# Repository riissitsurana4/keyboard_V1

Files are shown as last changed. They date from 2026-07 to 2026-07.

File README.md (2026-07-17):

# Keyboard_V1
Hello everyone!

This hardware project is a custom keyboard and  macro pad made using switches, a rotatory encoder, etc.

## PCB Design
### Keyboard 
The PCB was designed in **KiCad** and includes the following features:

* Cherry Mx Switches arranged in a matrix 
* Mini leds for underglow
* 2 rotary encoder
* NRF52840 as the MCU
* 1N4148 (diodes)
* 74HC14N and MT3608 to step up current for leds
* 74HC595 - Shift registers

The LEDs are placed under each key for per key under glow.
Using shift registers for columns.

https://kicanvas.org/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

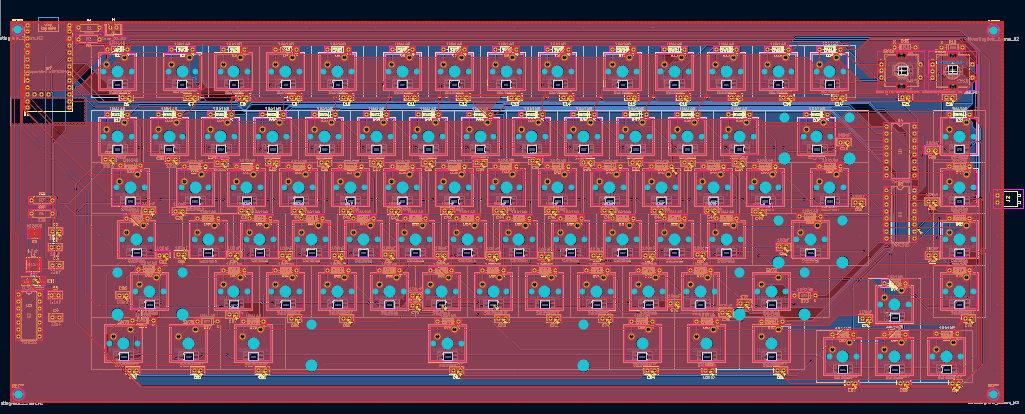
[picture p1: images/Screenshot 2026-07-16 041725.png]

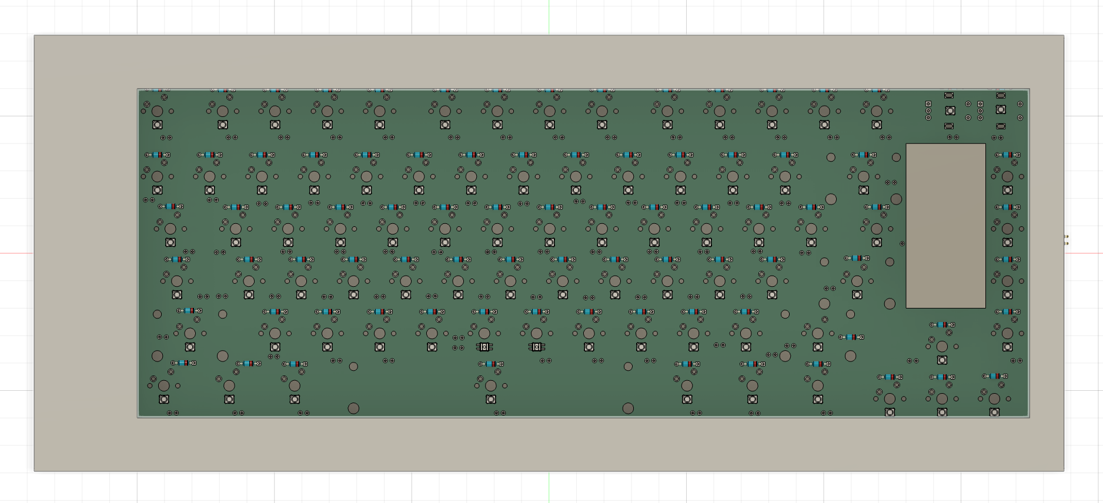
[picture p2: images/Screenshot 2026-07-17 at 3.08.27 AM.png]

### Macro Pad
The PCB was designed in **KiCad** and includes the following features:
* Cherry Mx Switches arranged in a matrix 
* 2 rotary encoder
* NRF52840 as the MCU
* 
https://kicanvas.org/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

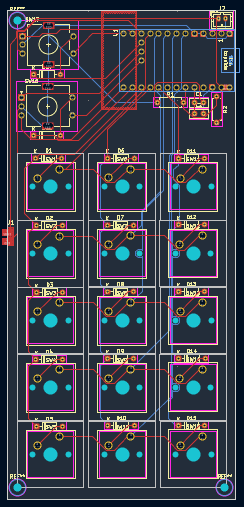
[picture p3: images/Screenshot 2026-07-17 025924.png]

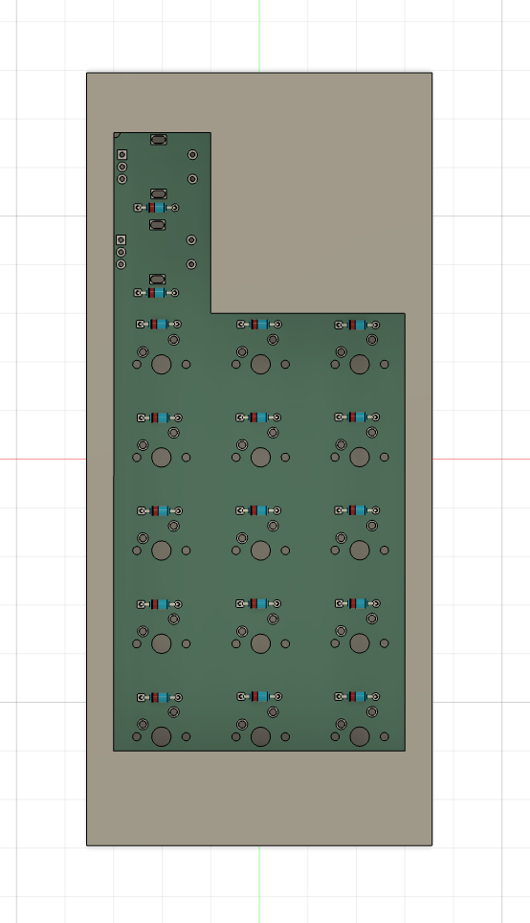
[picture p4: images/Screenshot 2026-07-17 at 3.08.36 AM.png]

Using the NRF in both of them as it can be used wirelessly together

Both of the pcbs have a battery connector.

## Firmware
The firmware for this project is written in ZMK.
MAjor part of the firmware is AI written, mainly the keyboard part as i could not get the shift resistors part to work by myself.
It is located in a different repo 
https://github.com/riissitsurana4/keyboard_zmk
You can find the latest build at https://github.com/riissitsurana4/keyboard_zmk/actions/runs/29620562583

## Instructions
If you want to create this keyboard for yourself, you can find the pcb and the case designs in this repo. The case is designed to be 3d printed. 
Please refer to the above firmware section to download the latest version. You will need to flash both the mcu's with the latest build. 

NOTE: For the macropad PCB you would need to order a perforated side pcb so that the copper pads will flow over to the sides and make the pogo pin connection better. 

## BOM
| Item | Part Number | Quantity | Link |
|---|---|---|---|
| Microcontroller | nRF52840 | 2 | https://robu.in/product/promicro-nrf52840-development-board/ |
| Diode | 1N4148 | | https://stackskb.com/store/1n4148-through-hole-diode/ |
| Shift Register | 74HC595 | 2 | https://robu.in/product/1-month-warranty-1354/ |
| Hex Schmitt Trigger | 74HC14N | 1 | https://robu.in/product/sn74hct14n-texas-instruments-logic-ic-inverter-hex-1-inputs-14-pins-dip-74hct14/ |
| DC-DC Boost Converter | MT3608 | 1 | https://robu.in/product/mt3608-xian-aerosemi-tech-boost-type-adjustable-2a-2v24v-sot-23-6-dc-dc-converters-rohs/ |
| Mini LEDs | SK6812 MINI |~90 |  |
| LiPo Battery | 2000 mAh | 1 |  |
| LiPo Battery | 300 mAh | 1 |  |
| Battery Connector | JST-PH 2.0 (2-pin) | 2 |  |
| Switches | Cherry-MX switches | ~100 |https://stackskb.com/store/akko-v3-cream-black-pro-switch-pack-of-45/  |

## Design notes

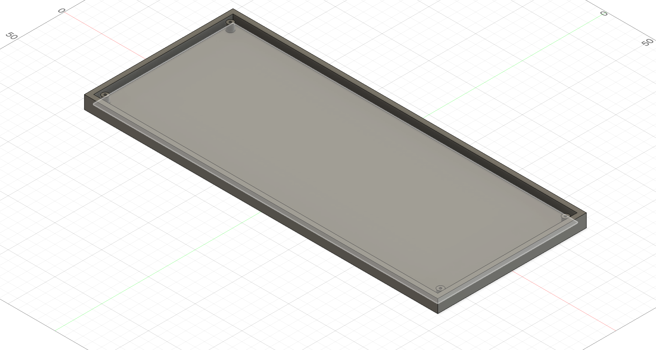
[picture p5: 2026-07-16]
images/Screenshot 2026-07-16 at 4.36.15 AM.png

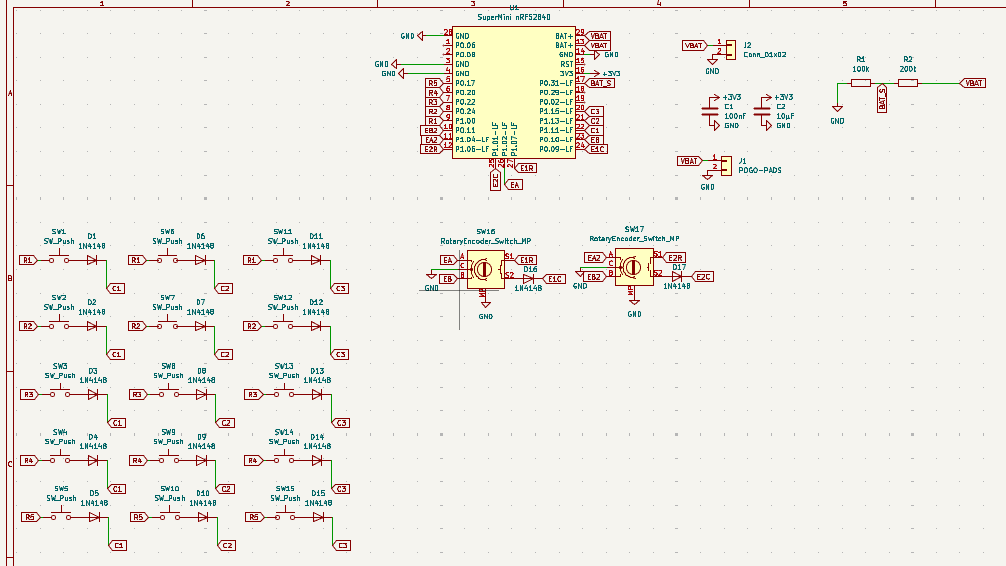
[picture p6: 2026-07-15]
images/Screenshot 2026-07-15 112258.png

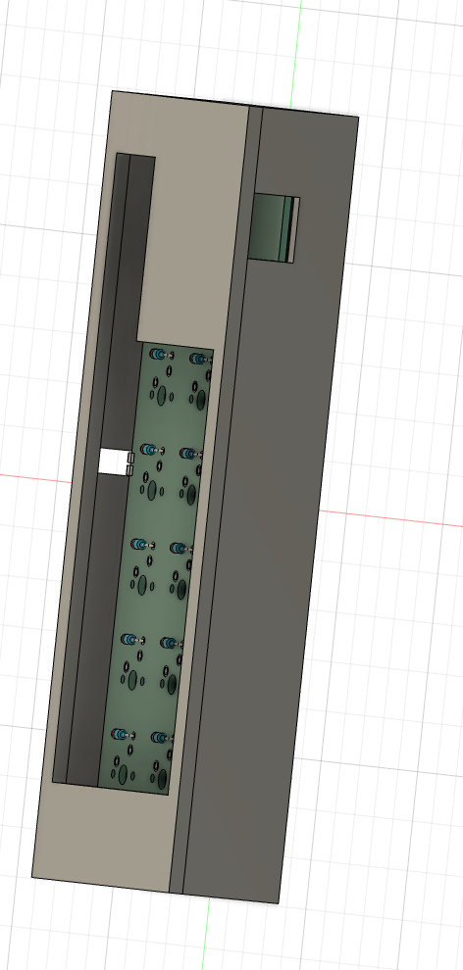
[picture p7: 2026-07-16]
images/Screenshot 2026-07-17 at 3.09.45 AM.png

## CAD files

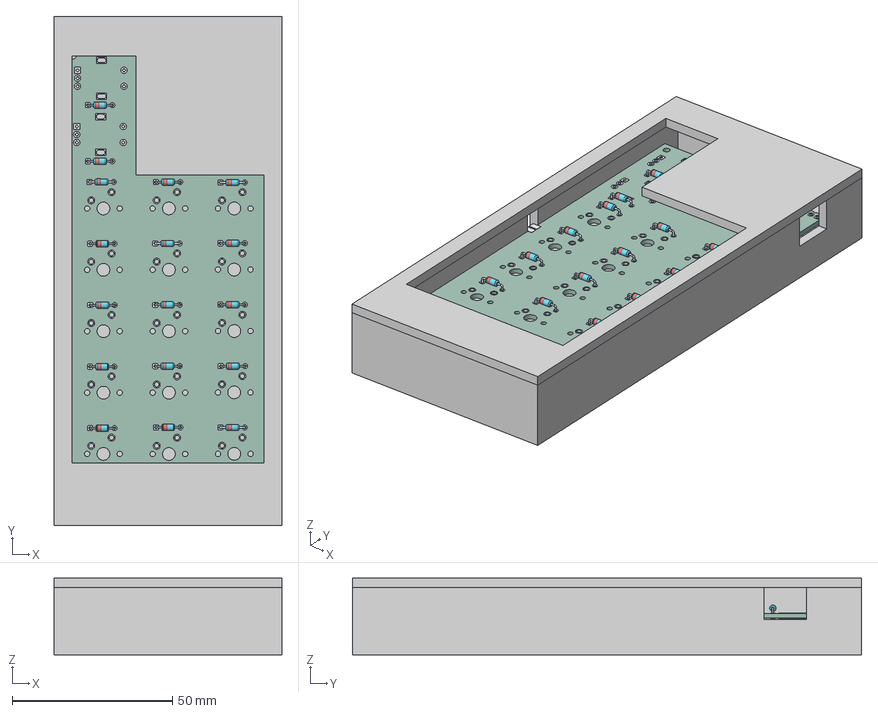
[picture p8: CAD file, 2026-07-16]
CASE - CAD/macropad_case.step
71.2 x 159.0 x 24.0 mm

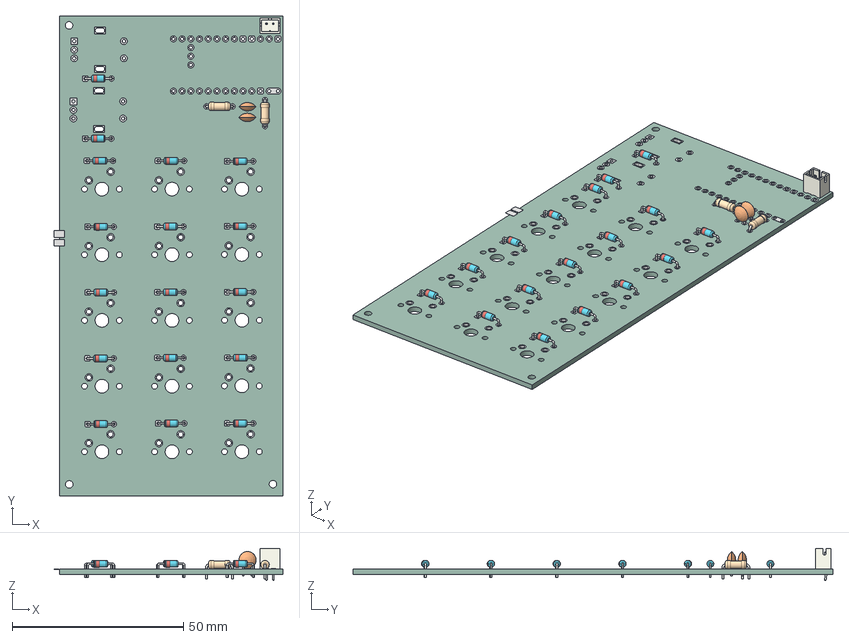
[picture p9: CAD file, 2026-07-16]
PCB/Macropad/macropad_pcb.step
66.7 x 140.0 x 9.40 mm
D_DO-35_SOD27_P7.62mm_Horizontal x 17
R_Axial_DIN0207_L6.3mm_D2.5mm_P7.62mm_Horizontal x 2
JST_PH_B2B-PH-K_1x02_P2.00mm_Vertical
C_Disc_D5.0mm_W2.5mm_P2.50mm x 2
macropad-v2_pad
macropad-v2_PCB

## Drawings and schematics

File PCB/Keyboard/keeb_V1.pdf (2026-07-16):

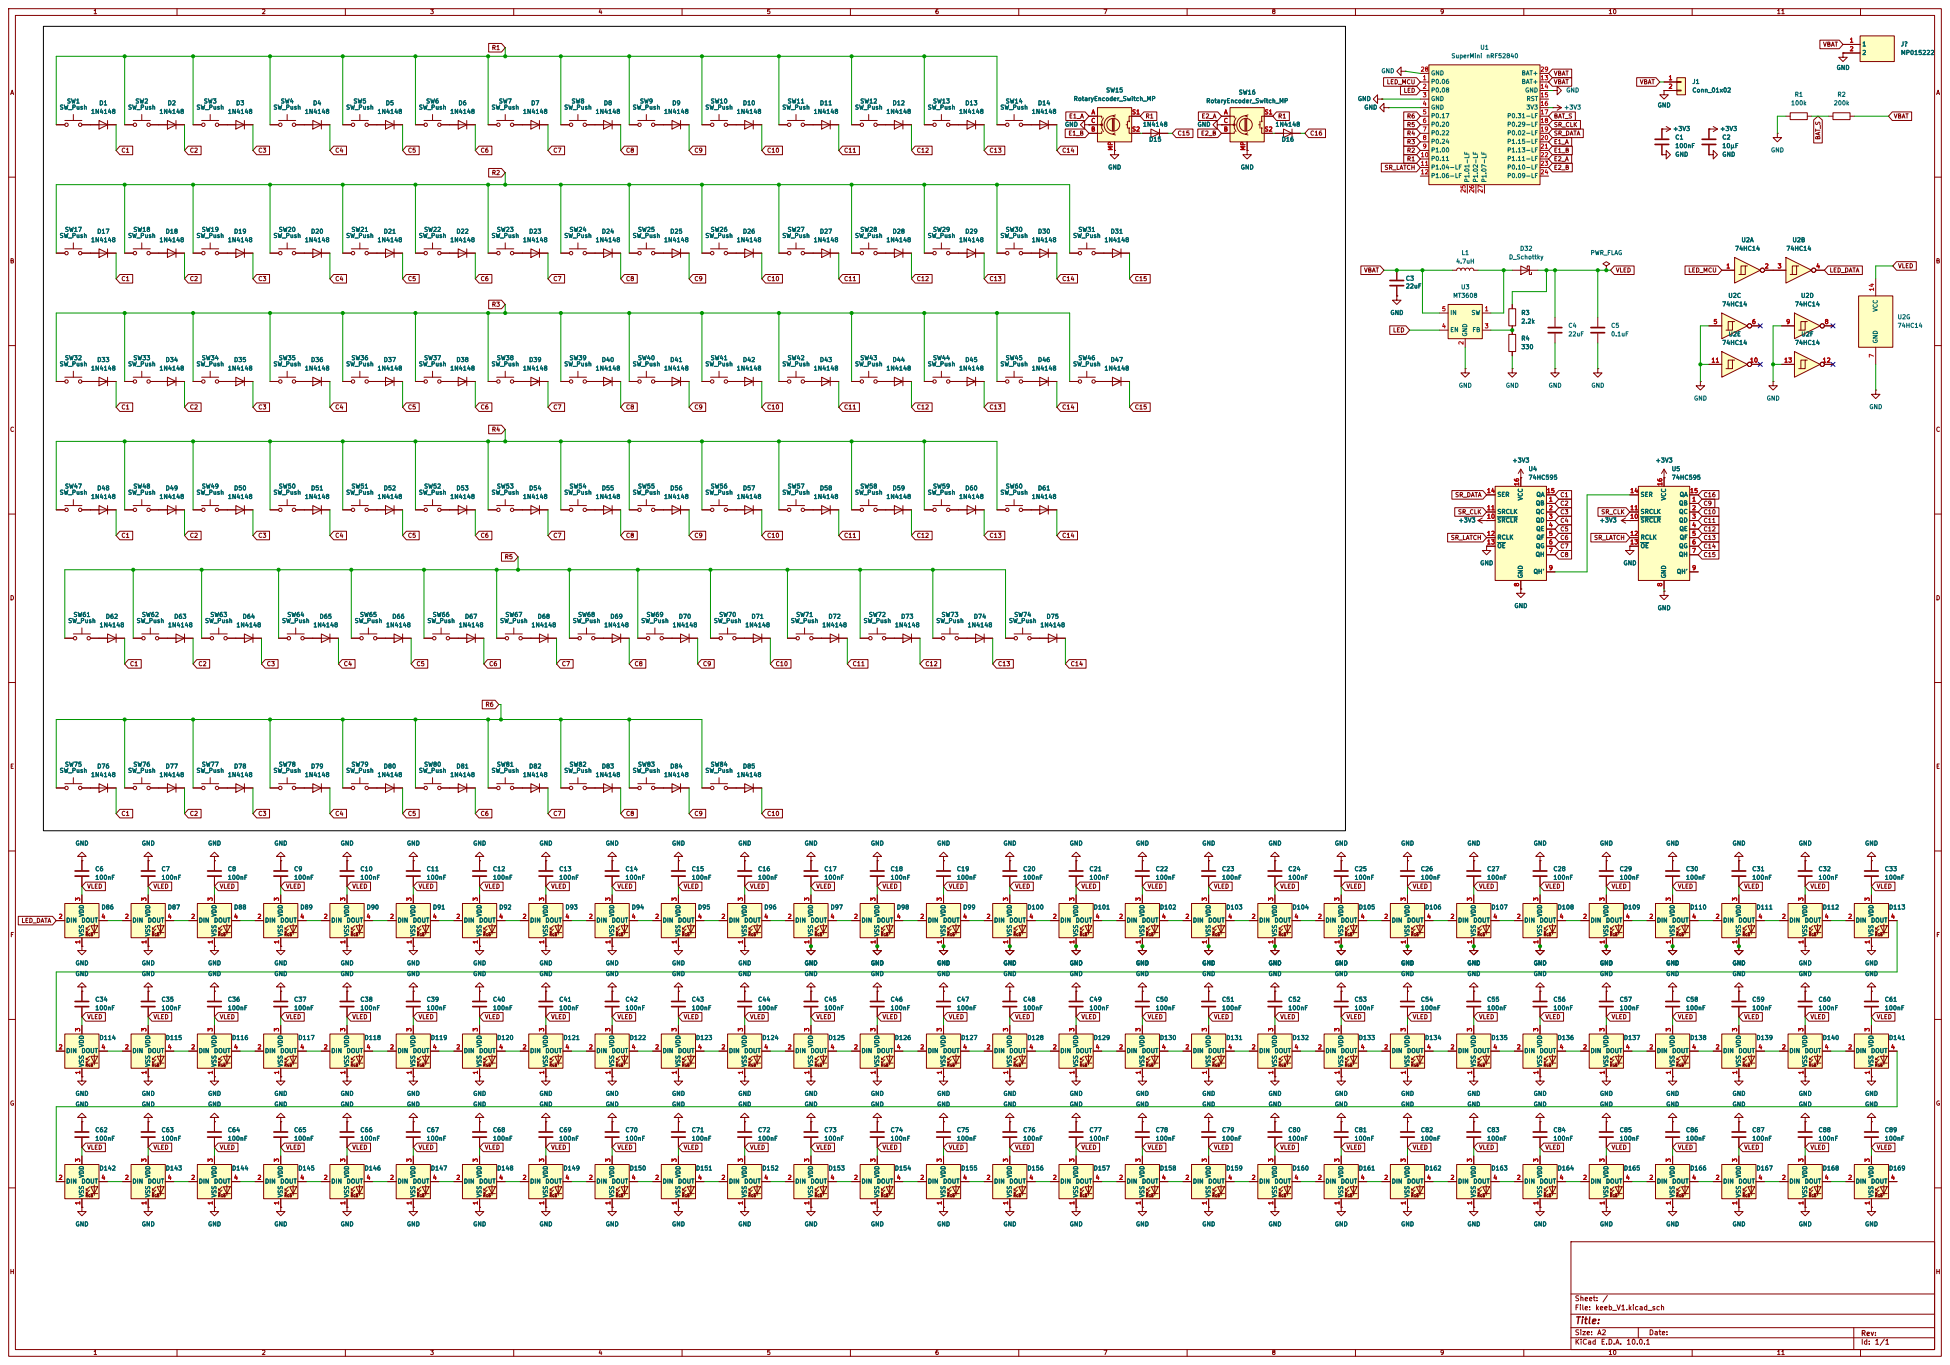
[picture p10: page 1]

14 RST 15 P0.31-LF 17 P0.29-LF 18 P0.02-LF 19 P1.15-LF 20 P1.13-LF 21 P1.11-LF 22 P0.09-LF 24 BAT+
VBAT VLED

3 DOUT 4D111 GNDVSS RGB 1 DIN

3 DOUT 4D105 GND GND VSS RGB 1 DIN 2 VDD

3 DOUT 4D102 GND VSS RGB 1 DIN 2 VDD

3 DOUT 4D104 GNDVSS RGB 1 DIN 2 VDD

3 DOUT 4D87 GND GNDVSS RGB 1 DIN 2 VDD

3 DOUT 4D91 VSS RGB 1 DIN

3 DOUT 4D92 GNDVSS RGB 1 DIN

3 DOUT 4D94 VSS RGB 1 DIN 2 VDD

3 DOUT 4 GND GND GND

3 DOUT 4D112 VSS RGB 1 DIN

3 DOUT 4D123 VSS RGB 1 DIN 2 VDD

3 DOUT 4D145 GND GND VSS RGB 1 DIN

3 DOUT 4D118 GND VSS RGB 1 DIN

100nF GND VSS RGB 1 DIN

3 DOUT 4D121 VSS RGB 1 DIN 2 VDD

3 DOUT 4D131 GND GNDVSS RGB 1 DIN 2 VDD

3 DOUT 4D117 GNDVSS RGB 1 DIN

3 DOUT 4D140 GND VSS RGB 1 DIN 2 VDD

3 DOUT 4D125 VSS RGB 1 DIN 2 VDD

3 DOUT 4D127 GND VSS RGB 1 DIN 2 VDD

3 DOUT 4D132 VSS RGB 1 DIN

3 DOUT 4D134 VSS RGB 1 DIN

3 DOUT 4D147 VSS RGB 1 DIN

3 DOUT 4D162 GND GND VSS RGB 1 DIN

3 DOUT 4D142 GND GNDVSS RGB 1 DIN 2 VDD

3 DOUT 4 GND GND GND GND GND GND

3 DOUT 4D157 VSS RGB 1 DIN 2 VDD

3 DOUT 4D156 VSS RGB 1 DIN 2 VDD

3 DOUT 4 GND GND GND GND

3 DOUT 4D158 VSS RGB 1 DIN

Size: A2 | Rev:
KiCad E.D.A. 10.0.1 | Id: 1/1

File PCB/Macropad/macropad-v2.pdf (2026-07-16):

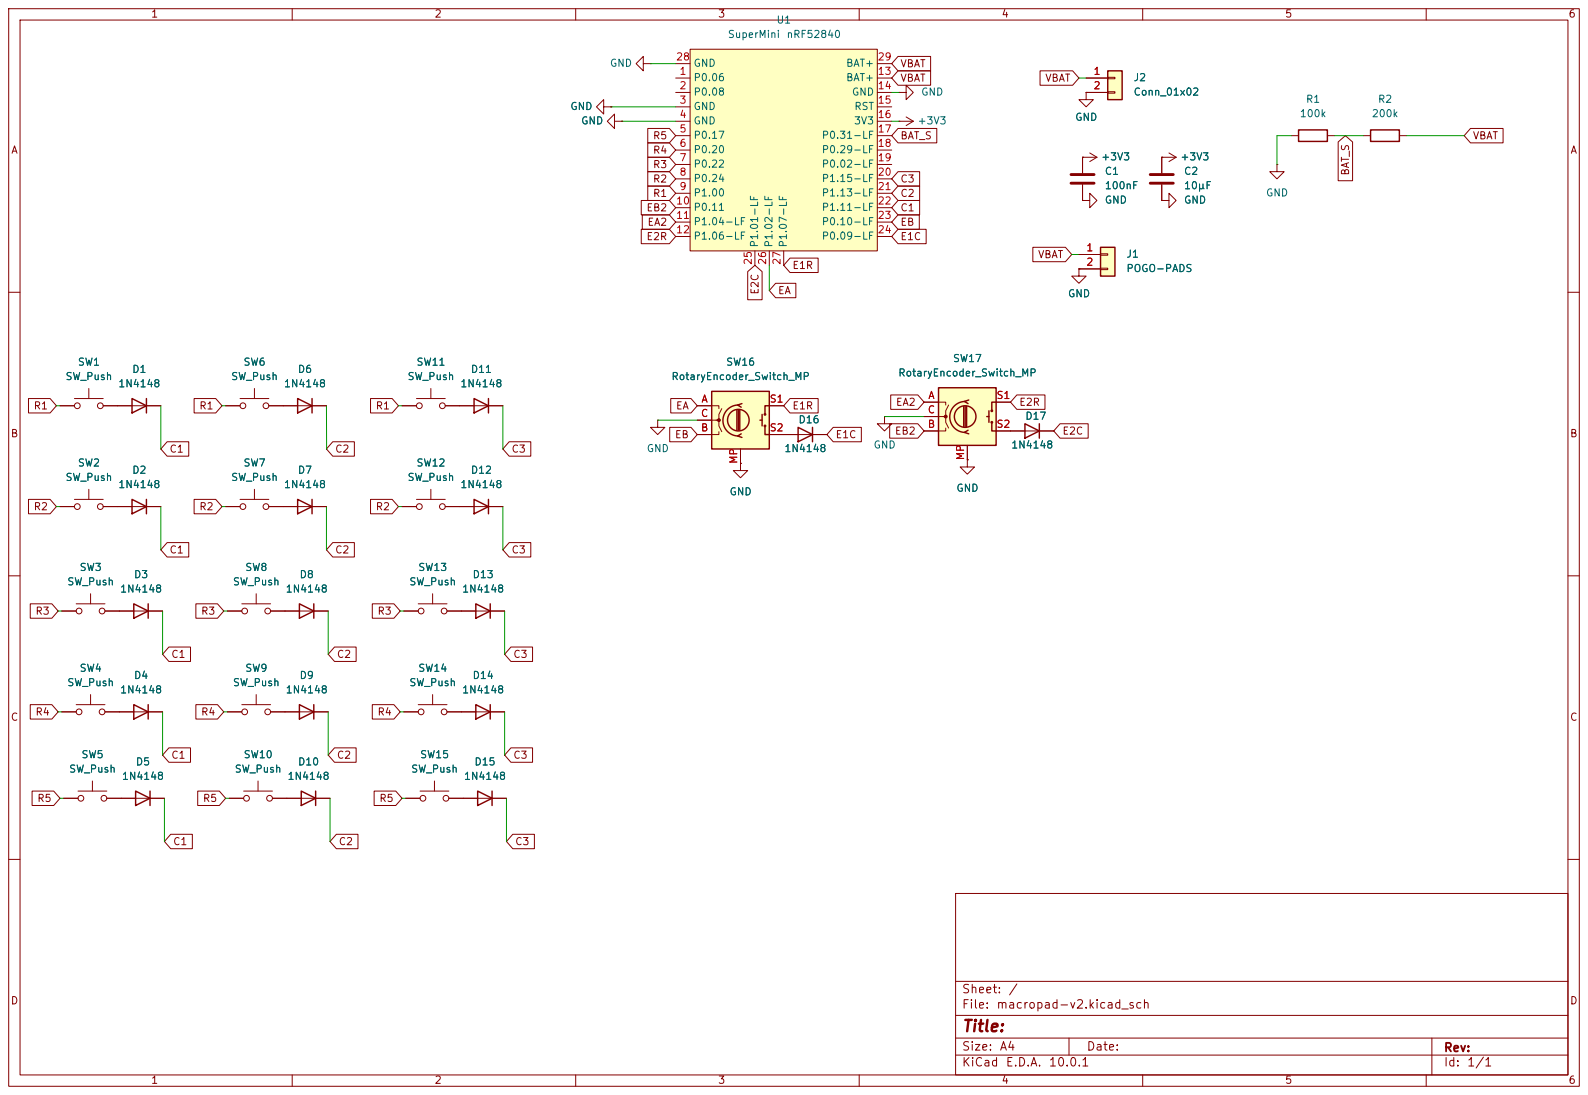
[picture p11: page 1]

Size: A4 | Rev:
KiCad E.D.A. 10.0.1 | Id: 1/1

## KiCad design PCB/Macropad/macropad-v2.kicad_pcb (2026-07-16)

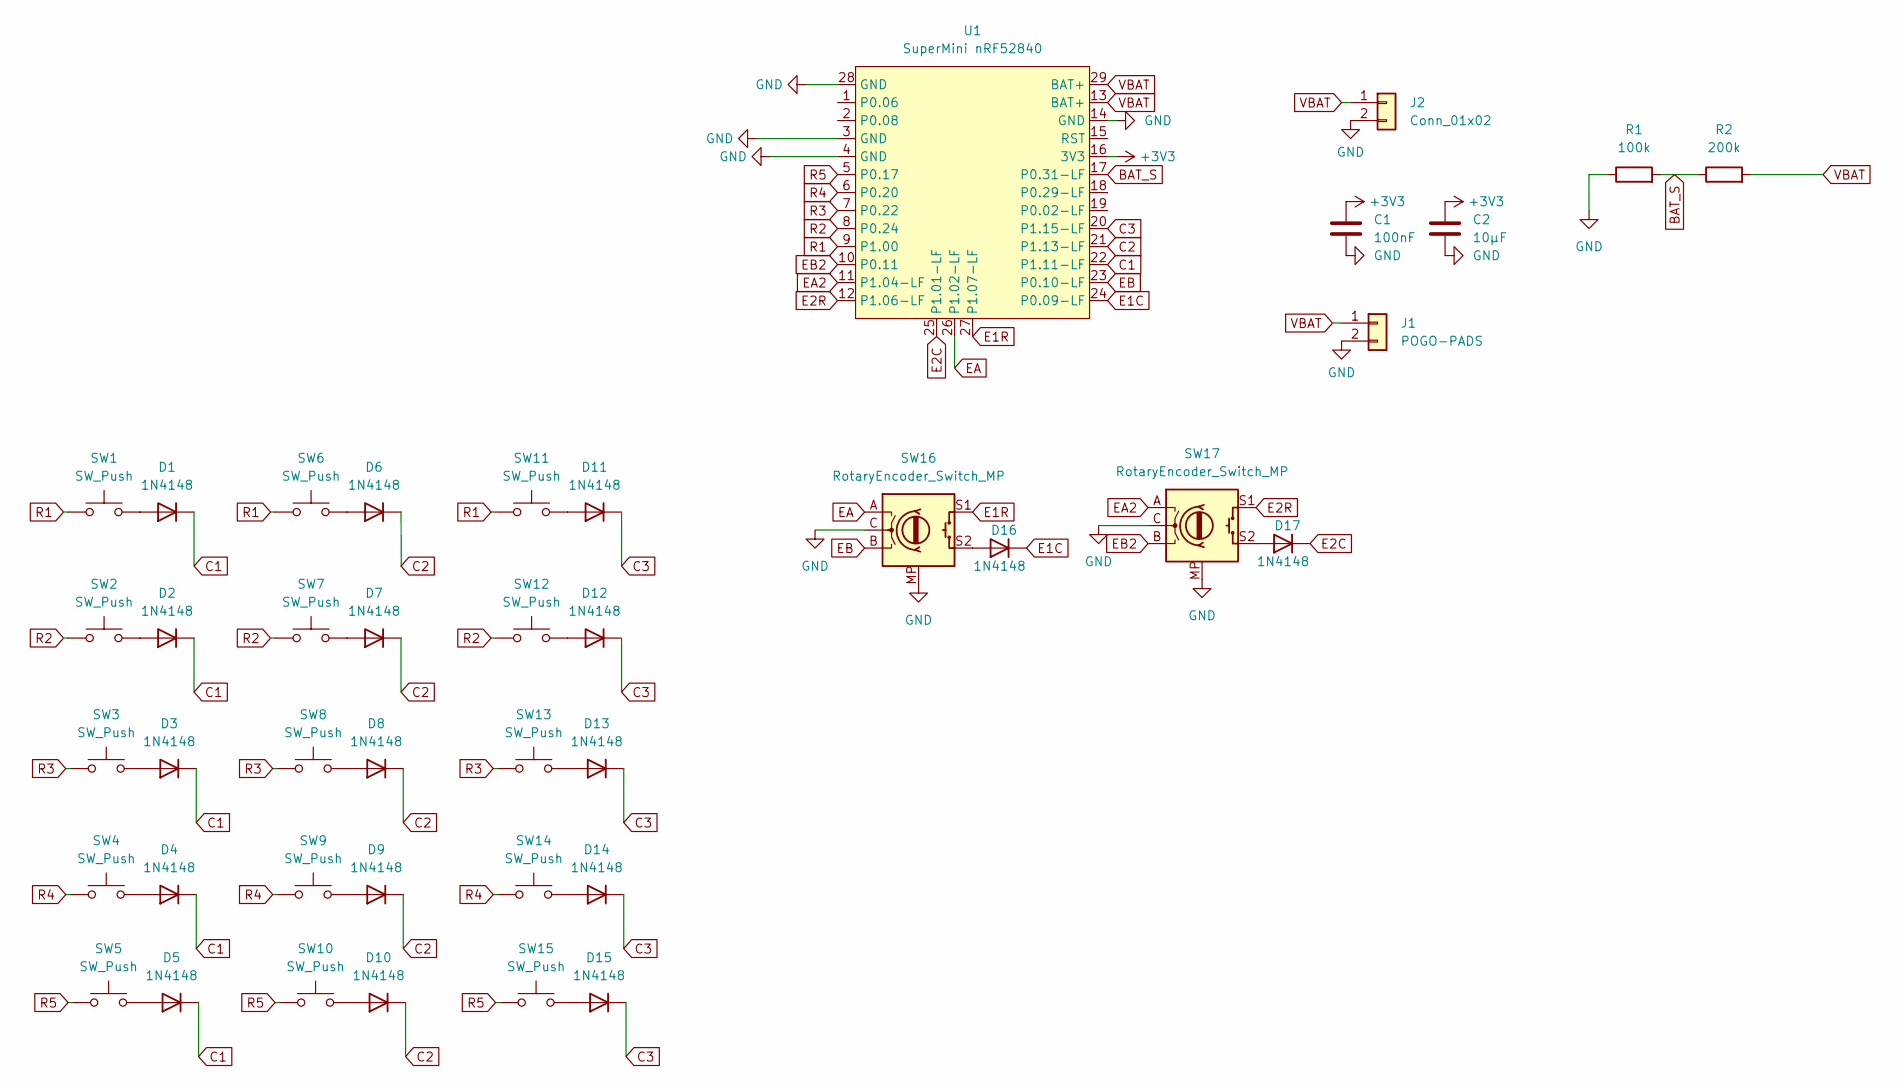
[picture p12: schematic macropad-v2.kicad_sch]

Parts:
C1: 100nF; C_Disc_D5.0mm_W2.5mm_P2.50mm
C2: 10µF; C_Disc_D5.0mm_W2.5mm_P2.50mm
D1, D2, D3, D4, D5, D6, D7, D8, D9, D10, D11, D12, D13, D14, D15, D16, D17: 1N4148; D_DO-35_SOD27_P7.62mm_Horizontal
J1: POGO-PADS; JST_PH_B2B-PH-K_1x02_P2.00mm_Vertical
J2: Conn_01x02; JST_PH_B2B-PH-K_1x02_P2.00mm_Vertical
R1: 100k; R_Axial_DIN0207_L6.3mm_D2.5mm_P7.62mm_Horizontal
R2: 200k; R_Axial_DIN0207_L6.3mm_D2.5mm_P7.62mm_Horizontal
SW1, SW2, SW3, SW4, SW5, SW6, SW7, SW8, SW9, SW10, SW11, SW12, SW13, SW14, SW15: SW_Push; SW_Cherry_MX_1.00u_PCB
SW16, SW17: RotaryEncoder_Switch_MP; RotaryEncoder_Alps_EC11E-Switch_Vertical_H20mm
U1: SuperMini nRF52840; nice_nano_AH_USBup

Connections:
+3V3: C1.1, C2.1, U1.16 (3V3)
BAT_S: R1.2, R2.1, U1.17 (P0.31-LF)
C1: D1.1 (K), D2.1 (K), D3.1 (K), D4.1 (K), D5.1 (K), U1.22 (P1.11-LF)
C2: D6.1 (K), D7.1 (K), D8.1 (K), D9.1 (K), D10.1 (K), U1.21 (P1.13-LF)
C3: D11.1 (K), D12.1 (K), D13.1 (K), D14.1 (K), D15.1 (K), U1.20 (P1.15-LF)
E1C: D16.1 (K), U1.24 (P0.09-LF)
E1R: SW16.S1, U1.27 (P1.07-LF)
E2C: D17.1 (K), U1.25 (P1.01-LF)
E2R: SW17.S1, U1.12 (P1.06-LF)
EA: SW16.A, U1.26 (P1.02-LF)
EA2: SW17.A, U1.11 (P1.04-LF)
EB: SW16.B, U1.23 (P0.10-LF)
EB2: SW17.B, U1.10 (P0.11)
GND: C1.2, C2.2, J1.2, J2.2, R1.1, SW16.C, SW16.MP, SW17.C, SW17.MP, U1.3 (GND), U1.4 (GND), U1.14 (GND), U1.28 (GND)
unnamed: D1.2 (A), SW1.2
unnamed: D2.2 (A), SW2.2
unnamed: D3.2 (A), SW3.2
unnamed: D4.2 (A), SW4.2
unnamed: D5.2 (A), SW5.2
unnamed: D6.2 (A), SW6.2
unnamed: D7.2 (A), SW7.2
unnamed: D8.2 (A), SW8.2
unnamed: D9.2 (A), SW9.2
unnamed: D10.2 (A), SW10.2
unnamed: D11.2 (A), SW11.2
unnamed: D12.2 (A), SW12.2
unnamed: D13.2 (A), SW13.2
unnamed: D14.2 (A), SW14.2
unnamed: D15.2 (A), SW15.2
unnamed: D16.2 (A), SW16.S2
unnamed: D17.2 (A), SW17.S2
R1: SW1.1, SW6.1, SW11.1, U1.9 (P1.00)
R2: SW2.1, SW7.1, SW12.1, U1.8 (P0.24)
R3: SW3.1, SW8.1, SW13.1, U1.7 (P0.22)
R4: SW4.1, SW9.1, SW14.1, U1.6 (P0.20)
R5: SW5.1, SW10.1, SW15.1, U1.5 (P0.17)
VBAT: J1.1, J2.1, R2.2, U1.13 (BAT+), U1.29 (BAT+)

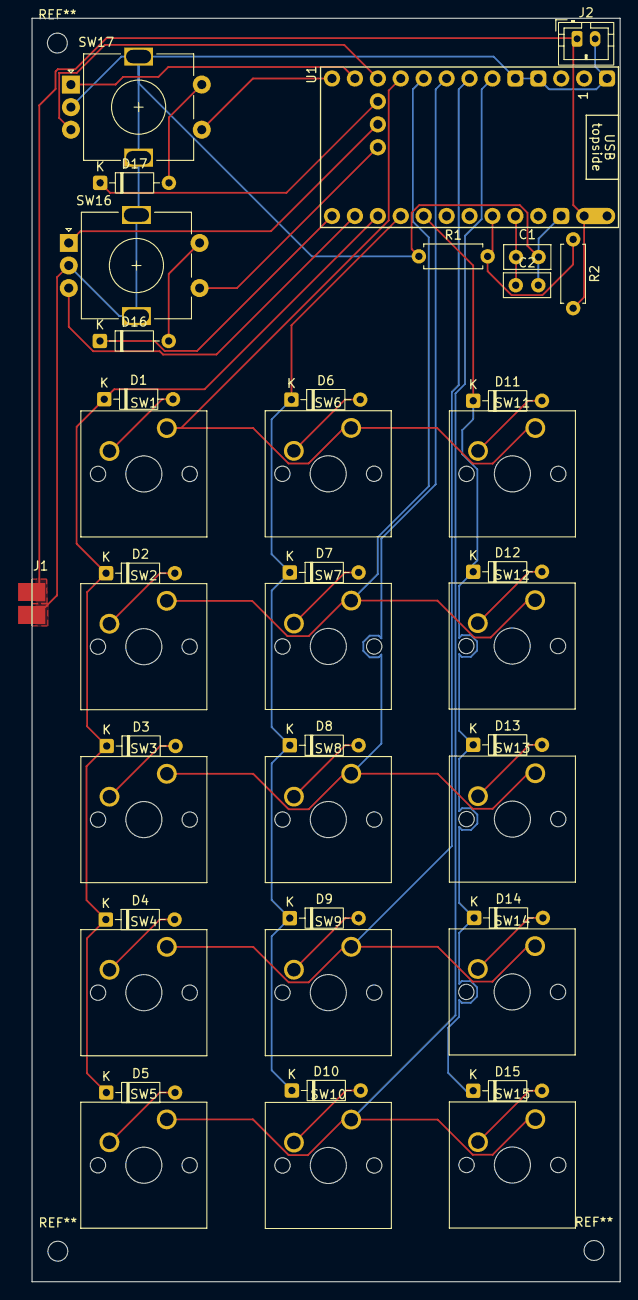
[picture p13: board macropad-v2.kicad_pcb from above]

Board: 2 copper layers, 65.2 x 140.0 mm, 41 parts (0 on the bottom side), 37 nets.

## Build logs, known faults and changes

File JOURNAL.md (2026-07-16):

---
title: "Keyboard_V1"
author: "riissitsurana"
description: "My first Keyboard with a twist"
created_at: "2026-05-26"
---

# May 26th, 2026: Started working on things

Started this project, went through a few things on the internet and decided to use nRF52840 Dev board as the main micro-controller because it is usually used in wireless keyboard.
Also decided to use Xiao 2040 for the dock-able screen part which will be hardwired as that thing will only consist of a screen, MCU and battery. 
Also worked on the schematic part, figured out the layout, number of switches and encoders, battery stuff, etc.
This is my first time working on something this big... Soo it took me some time to figure things out like battery, resisters, shift resisters, etc.
Finally finished the schematic, learned a few things about MT3608 and 74HC14, which i used to convert/step up the 3.3v to 5v which is good for the leds.
Also decided to have per key under-glow led and added two encoders instead of one. 

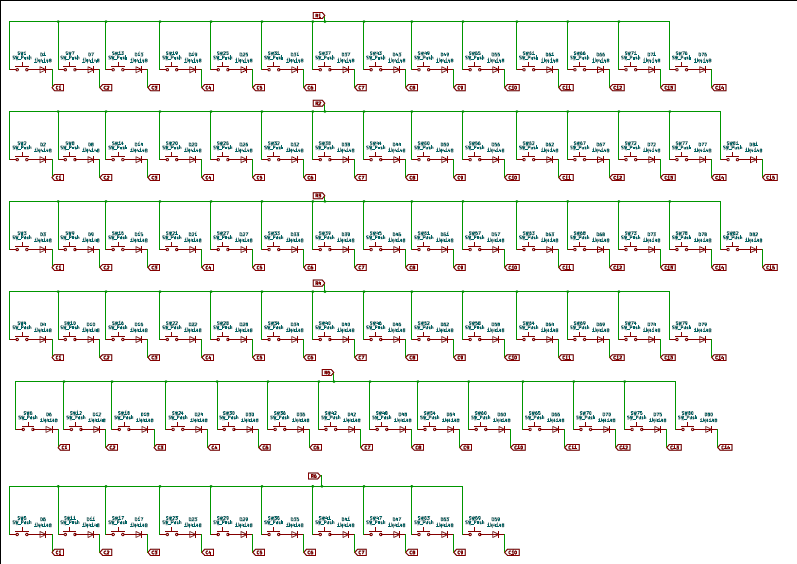
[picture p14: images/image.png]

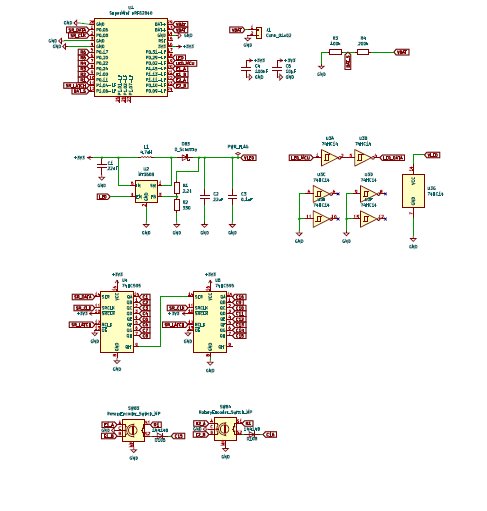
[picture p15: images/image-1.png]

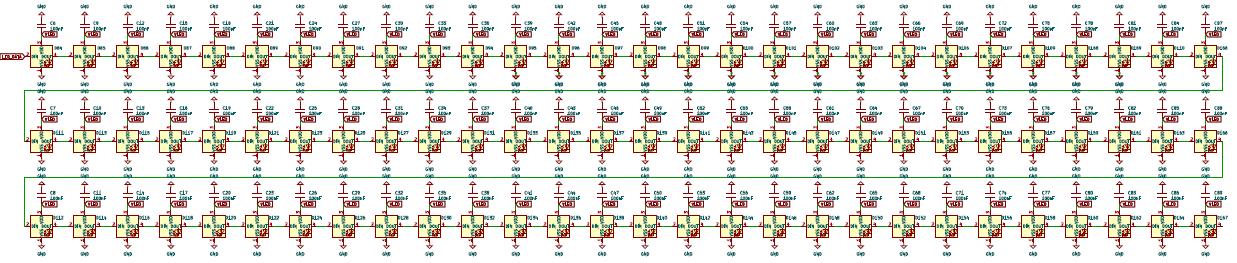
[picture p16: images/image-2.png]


NOTE: This was done over 3 - 4 days cause i was researching and testing new stuff. 

Also this is the layout i decided to go with (E1 and E2 are encoders)
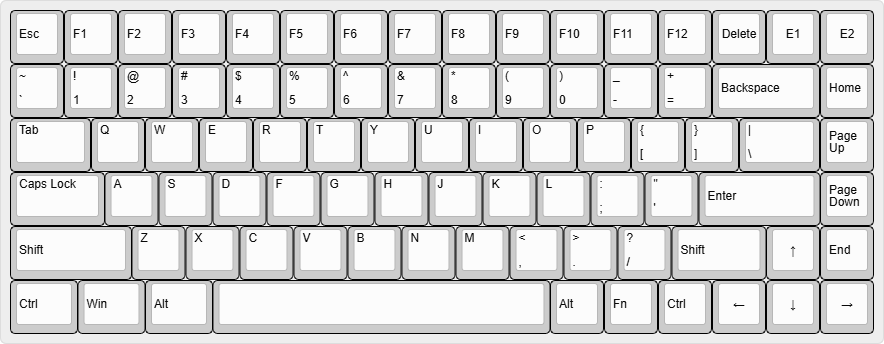
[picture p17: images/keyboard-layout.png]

**Total time spent: 6h**

# May 30th, 2026: PCB time
First i updated the layout in the KLE which i then exported and used in the KLE kicad plugin.
With the help of claude and a plugin for placing the keys and diodes i finished up the placing part really quickly. 
I also decided to place things like the MCU, battery and all the other stuff on the left side as the right side will have the magnets which will help me dock the screen and any other dock able thing if i plan to make.
I wrote a script with the help of claude to place the leds and its corresponding capacitor near the switches. 

Then i started one of the most difficult and time taking task for me which is routing. 
First i started doing the rows followed by the leds an other things like the battery sense resistors and the MT3608. After that i started routing the diodes to the switches (easiest part). Then i started with leds which was a little bit difficult. I moved the led capacitors again and again to find them the perfect place. While routing the leds I realized that I had not connected the columns. The 74HC595 shift register was on the other side of the pcb and made it difficult to connect it to the first few columns cause the led and the rows routing had taken up the few paths to run the long lines of copper to connect them.

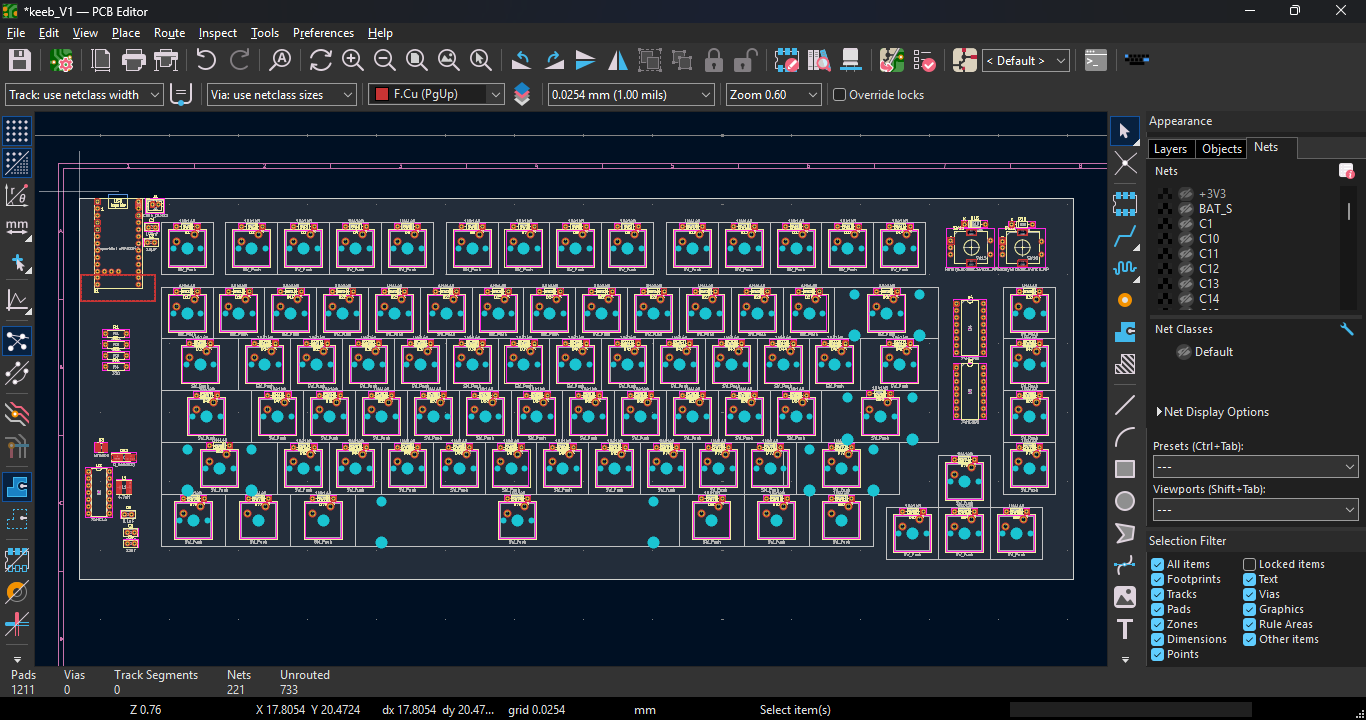
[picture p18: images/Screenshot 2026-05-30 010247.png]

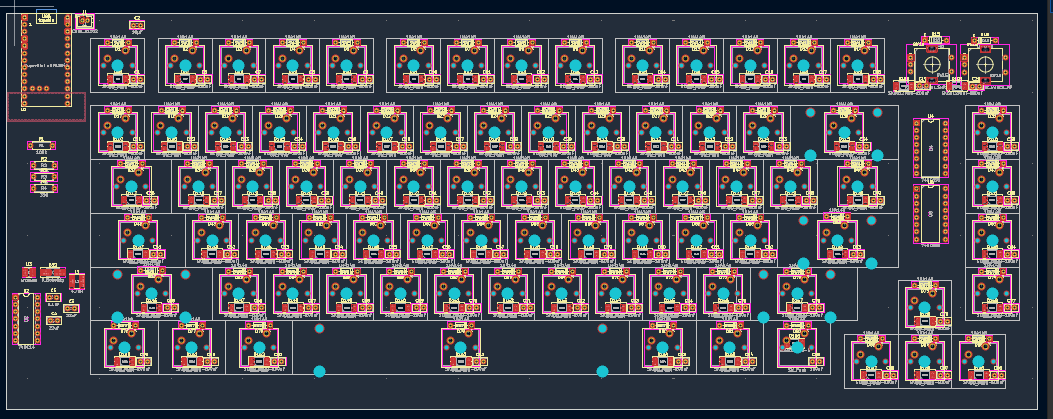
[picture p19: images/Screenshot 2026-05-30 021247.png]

**Total time spent: 4h**

# June 20th, 2026: PCB time continued 
After not touching this project for the last few days, i came back to this with more research and a change in idea. I have decided to add a dock-able macropad instead of a screen on the side of the keyboard. I moved the screen to the top side. In theory/planning i have decided to make it such that it will be small and will dock/connect/snap on to the keyboard or the macropad. The screen will still be the only component which will need a wired connection to run. 

The macropad will have 16 keys and a encoder, a nRF52840 (same one as the kb) and maybe per key under glow like the kb.

Now update on the pcb of the main KB, i am still working on routing everything. The columns are really difficult to route. For some reason (which i soooo not remember), the capacitors had moved places, so i had to move them all again. Lesson learnt, do not work on pcb while sleepy 

Same day update: Nearly finished the columns routing and the led routing. 
Finally finished the whole routing for the main KB pcb...... Rerouted a few things, made to many connections using vias.
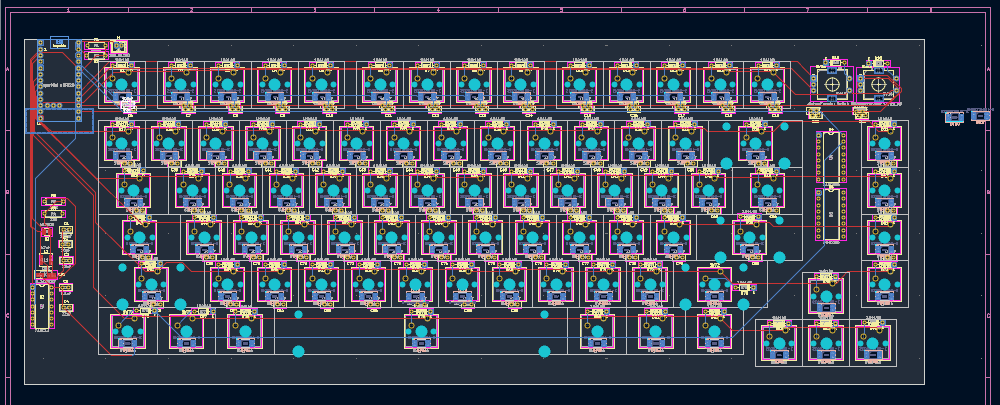
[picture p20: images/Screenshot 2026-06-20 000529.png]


**Total time spent: 6h**

# June 25th, 2026: Schematic 2 (Macro Pad)
Fixed all the drc errors for the main KB; ALso added the pogo pins to the pcb and schematic.

Started working on the schematic of the macropad which was way easier than the Kb. . Key features include 16 keys, 1 encoder and nRF52840.

Also started working on the pcb after i completed the schematic designing. Completed the PCB, redid the design multiple times, still figuring out what to add on the receiving side of the pogo pins. Finally the macro pad consists of 15 keys (3*5 matrix), 2 encoders and a nRF52840. 
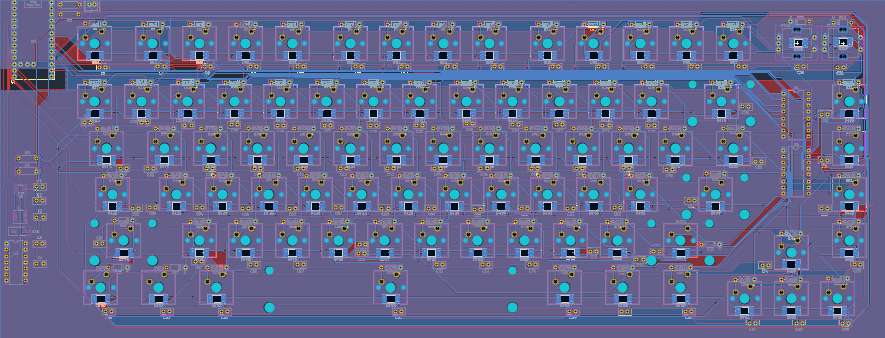
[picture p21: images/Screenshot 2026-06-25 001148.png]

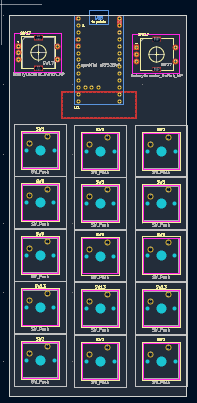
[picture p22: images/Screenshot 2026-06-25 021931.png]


**Total time spent: 5h**

# July 15th, 2026: Finishing the PCB design and starting Case designing
I finally decided to add copper pads on the surface of the pcb and make the case in such a way that the pogo pins will rest on top of the pcb.

Added mounting holes on the pcbs and then started working on the case.

### CASE 1: Keyboard
Started working on the case design of the main keyboard. At first i thought that i would make a typing angle in the keyboard and started working on it. Later i decided to just make a normal base because i was running into problems while making the angle thingy. I was not able to place the pcb properly according to the angle.... I will learn more about 3d des and come back to this in my next kb version.

Then i made small changes to the initiall design of the case and also the positioning of the pogo pins on the pcb. I then imported the pcb into fusion so i could add proper mounting holes and stuff. 

Later I made cutouts for pogo pins and charging port and decided not to make a top yet.
Also decided to not make a different compartment for battery and will keep it just below the pcb, hopefully it should fit there.

**Lapse links and Images**
https://lapse.hackclub.com/timelapse/A4WhkUfEeMN5
https://lapse.hackclub.com/timelapse/ywpzmXBKPaUQ

**Updated and final keyboard pcb**


# July 16th, 2026: Macro-pad case and organizing repo.

### CASE 2: Macro-pad
Made the macro pad case similar to the keyboard case. Made the cutouts and stuff...

Also made a covering for both of the cases and tried putting them both together in fusion trying to see if my design is perfect or not.

While making the final part, i forgot to press resume on my lapse..... only a few minutes of work though.

After making the cases, i started uploading all the files to this repo and tried to make the repo perfect.

**Lapse links and Images**
https://lapse.hackclub.com/timelapse/bDEIflPvGz7Y

**Updated and final macro pad pcb**


**Images of completed cases**


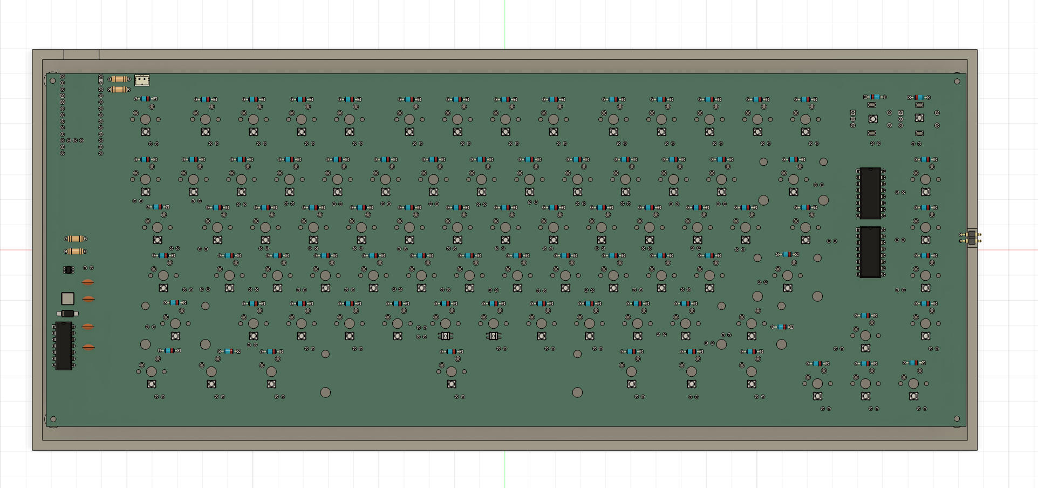
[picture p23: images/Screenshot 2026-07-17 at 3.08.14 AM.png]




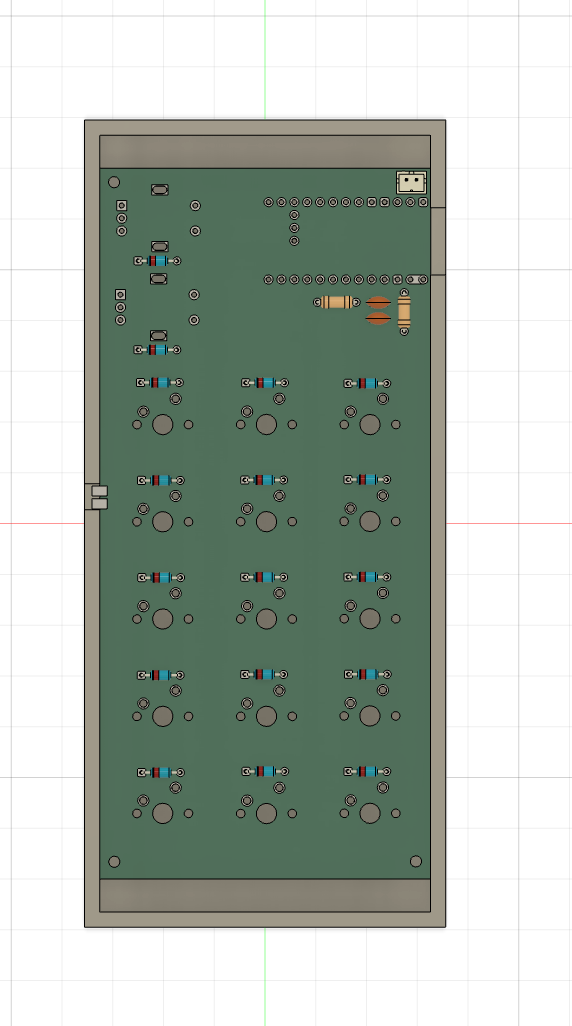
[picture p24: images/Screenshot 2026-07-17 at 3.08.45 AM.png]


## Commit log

2026-07-16 uploading files
    [keeb_V1.kicad_sch, keyboard_sch.kicad_sch, macropad-v2.kicad_pcb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]
2026-07-16 uploading and updating
    [keeb_V1-B_Cu.gbr, keeb_V1-B_Mask.gbr, keeb_V1-B_Paste.gbr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]
